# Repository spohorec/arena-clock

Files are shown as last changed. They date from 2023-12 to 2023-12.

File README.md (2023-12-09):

# Mass Destruction Arena Clock

A simple and robust solution for combat robotics arena-side match clock. The clock consists of a PCB for power + logic, 2 sets of 3x 6" seven-segment digits (one for competitors, one for audience viewing), and a nucleo-L412KB for control. The clock is controlled via USB UART and a python gui.

## READMEs

[Firmware README](firmware/README.md)

[GUI README](gui/README.md)

[PCB README](pcb/README.md)

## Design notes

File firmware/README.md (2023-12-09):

# Arena Clock Firmware

This firmware uses [platformio](https://platformio.org/) for build management. It runs on a [ST Nucleo-L412KB](https://www.st.com/en/evaluation-tools/nucleo-l412kb.html) on a custom carrier board (see [pcb](../pcb/)).

The CubeMX project configuration is generated in headless mode during the project build. You must change the value of the `CUBE` varibale in `lib/cube/generate_cube_code.sh` to point to your installation of STM32CubeMX. Note that this script will likely not work on a Windows machine without modification. If developing on Windows, the call to `generate_stm32_cube_sources()` in `extra.py` can be commented out and the required code can be manually generated using the STM32CubeMx GUI and then moved to `lib/cube/Src/` and `lib/cube/Inc`. The patch file adds an include directive to include `main_loop.h` and call `MainLoop()` after initialization is completed in `main()`. This can also be added manually.

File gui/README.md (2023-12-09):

# GUI To control clock

## Requirements

* Python 3.6 +
* Modules: PyQt5, sys, serial

## How to use:

Plug USB into nucleo and computer and run
`python3.6 gui.py [insert serial port here (COMX or /dev/ttyXYZ)]`

Type desired time (min:sec) into time entry. Click "set time" to send to the nucleo. The "clear" button zeroes the time on the clock. The start/pause button controls when the clock counts down. Once the timer has been started, it must count to zero or be cleared before a new time can be entered.

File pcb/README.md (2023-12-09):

# Arena Clock PCB

This PCB project was made with Kicad 6.0

## Bill of Materials

TODO

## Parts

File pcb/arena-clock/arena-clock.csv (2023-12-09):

Source: | /home/spocky/arena-clock/pcb/arena-clock/arena-clock.kicad_sch
Date: | Mon 20 Nov 2023 06:52:53 PM EST
Tool: | Eeschema 6.0.10-86aedd382b~118~ubuntu18.04.1
Generator: | /usr/share/kicad/plugins/bom_csv_grouped_by_value.py
Component Count: | 128
Individual Components:
Item | Qty | Reference(s) | Value | LibPart | Footprint | Datasheet
 |  | C1 | C_Small | Device:C_Small | Capacitor_SMD:C_0805_2012Metric_Pad1.18x1.45mm_HandSolder | ~
 |  | C2 | C_Small | Device:C_Small | Capacitor_SMD:C_0805_2012Metric_Pad1.18x1.45mm_HandSolder | ~
 |  | C3 | C_Small | Device:C_Small | Capacitor_SMD:C_0805_2012Metric_Pad1.18x1.45mm_HandSolder | ~
 |  | C4 | 10u | Device:C_Small | Capacitor_SMD:C_0805_2012Metric_Pad1.18x1.45mm_HandSolder | ~
 |  | C5 | 10u | Device:C_Small | Capacitor_SMD:C_0805_2012Metric_Pad1.18x1.45mm_HandSolder | ~
 |  | C6 | C_Small | Device:C_Small | Capacitor_SMD:C_0805_2012Metric_Pad1.18x1.45mm_HandSolder | ~
 |  | C7 | 0.1u | Device:C_Small | Capacitor_SMD:C_0805_2012Metric_Pad1.18x1.45mm_HandSolder | ~
 |  | C8 | 0.1u | Device:C_Small | Capacitor_SMD:C_0805_2012Metric_Pad1.18x1.45mm_HandSolder | ~
 |  | C9 | 0.1u | Device:C_Small | Capacitor_SMD:C_0805_2012Metric_Pad1.18x1.45mm_HandSolder | ~
 |  | C10 | 0.1u | Device:C_Small | Capacitor_SMD:C_0805_2012Metric_Pad1.18x1.45mm_HandSolder | ~
 |  | D1 | D_Schottky | Device:D_Schottky | Diode_THT:D_A-405_P7.62mm_Horizontal | ~
 |  | J1 | SPEAKER ENABLE | Connector_Generic:Conn_01x02 | TerminalBlock_Phoenix:TerminalBlock_Phoenix_PT-1,5-2-3.5-H_1x02_P3.50mm_Horizontal | ~
 |  | J2 | DIGIT1 | Connector_Generic:Conn_01x09 | TerminalBlock_Phoenix:TerminalBlock_Phoenix_PT-1,5-9-3.5-H_1x09_P3.50mm_Horizontal | ~
 |  | J3 | DIGIT2 | Connector_Generic:Conn_01x09 | TerminalBlock_Phoenix:TerminalBlock_Phoenix_PT-1,5-9-3.5-H_1x09_P3.50mm_Horizontal | ~
 |  | J4 | DIGIT3 | Connector_Generic:Conn_01x09 | TerminalBlock_Phoenix:TerminalBlock_Phoenix_PT-1,5-9-3.5-H_1x09_P3.50mm_Horizontal | ~
 |  | J5 | DIGIT4 | Connector_Generic:Conn_01x09 | TerminalBlock_Phoenix:TerminalBlock_Phoenix_PT-1,5-9-3.5-H_1x09_P3.50mm_Horizontal | ~
 |  | J6 | DIGIT5 | Connector_Generic:Conn_01x09 | TerminalBlock_Phoenix:TerminalBlock_Phoenix_PT-1,5-9-3.5-H_1x09_P3.50mm_Horizontal | ~
 |  | J7 | DIGIT6 | Connector_Generic:Conn_01x09 | TerminalBlock_Phoenix:TerminalBlock_Phoenix_PT-1,5-9-3.5-H_1x09_P3.50mm_Horizontal | ~
 |  | J8 | AUX 12V OUT | Connector_Generic:Conn_01x02 | Connector_PinHeader_2.54mm:PinHeader_1x02_P2.54mm_Vertical | ~
 |  | J9 | Conn_01x03_Male | Connector:Conn_01x03_Male | Connector_PinHeader_2.54mm:PinHeader_1x03_P2.54mm_Vertical | ~
 |  | J10 | Conn_01x03_Male | Connector:Conn_01x03_Male | Connector_PinHeader_2.54mm:PinHeader_1x03_P2.54mm_Vertical | ~
 |  | J11 | 12V POW CONN | Connector_Generic:Conn_01x02 | Connector_PinHeader_2.54mm:PinHeader_1x02_P2.54mm_Vertical | ~
 |  | J12 | 5V POW CONN | Connector_Generic:Conn_01x02 | Connector_PinHeader_2.54mm:PinHeader_1x02_P2.54mm_Vertical | ~
 |  | J13 | AUX SINK | Connector_Generic:Conn_01x06 | Connector_PinHeader_2.54mm:PinHeader_1x06_P2.54mm_Vertical | ~
 |  | J14 | AUX GPIO | Connector_Generic:Conn_01x05 | Connector_PinHeader_2.54mm:PinHeader_1x05_P2.54mm_Vertical | ~
 |  | J15 | Barrel_Jack | Connector:Barrel_Jack_Switch_MountingPin | Connector_BarrelJack:BarrelJack_Kycon_KLDX-0202-xC_Horizontal | ~
 |  | J16 | CN3 Breakout | Connector:Conn_01x15_Female | Connector_PinHeader_2.54mm:PinHeader_1x15_P2.54mm_Vertical | ~
 |  | J17 | CN3 | Connector:Conn_01x15_Female | Connector_PinHeader_2.54mm:PinHeader_1x15_P2.54mm_Vertical | ~
 |  | J18 | CN4 | Connector:Conn_01x15_Female | Connector_PinHeader_2.54mm:PinHeader_1x15_P2.54mm_Vertical | ~
 |  | J19 | CN4 Breakout | Connector:Conn_01x15_Female | Connector_PinHeader_2.54mm:PinHeader_1x15_P2.54mm_Vertical | ~
 |  | R1 | 0 | Device:R_Small | Resistor_SMD:R_0805_2012Metric_Pad1.20x1.40mm_HandSolder | ~
 |  | R2 | 100k | Device:R_Small | Resistor_SMD:R_0805_2012Metric_Pad1.20x1.40mm_HandSolder | ~
 |  | R3 | 100k | Device:R_Small | Resistor_SMD:R_0805_2012Metric_Pad1.20x1.40mm_HandSolder | ~
 |  | R4 | 0 | Device:R_Small | Resistor_SMD:R_0805_2012Metric_Pad1.20x1.40mm_HandSolder | ~
 |  | R5 | 100k | Device:R_Small | Resistor_SMD:R_0805_2012Metric_Pad1.20x1.40mm_HandSolder | ~
 |  | R6 | 100k | Device:R_Small | Resistor_SMD:R_0805_2012Metric_Pad1.20x1.40mm_HandSolder | ~
 |  | R7 | 0 | Device:R_Small | Resistor_SMD:R_0805_2012Metric_Pad1.20x1.40mm_HandSolder | ~
 |  | R8 | 15 | Device:R_Small | Resistor_SMD:R_0805_2012Metric_Pad1.20x1.40mm_HandSolder | ~
 |  | R9 | 15 | Device:R_Small | Resistor_SMD:R_0805_2012Metric_Pad1.20x1.40mm_HandSolder | ~
 |  | R10 | 15 | Device:R_Small | Resistor_SMD:R_0805_2012Metric_Pad1.20x1.40mm_HandSolder | ~
 |  | R11 | 15 | Device:R_Small | Resistor_SMD:R_0805_2012Metric_Pad1.20x1.40mm_HandSolder | ~
 |  | R12 | 15 | Device:R_Small | Resistor_SMD:R_0805_2012Metric_Pad1.20x1.40mm_HandSolder | ~
 |  | R13 | 15 | Device:R_Small | Resistor_SMD:R_0805_2012Metric_Pad1.20x1.40mm_HandSolder | ~
 |  | R14 | 15 | Device:R_Small | Resistor_SMD:R_0805_2012Metric_Pad1.20x1.40mm_HandSolder | ~
 |  | R15 | 15 | Device:R_Small | Resistor_SMD:R_0805_2012Metric_Pad1.20x1.40mm_HandSolder | ~
 |  | R16 | 15 | Device:R_Small | Resistor_SMD:R_0805_2012Metric_Pad1.20x1.40mm_HandSolder | ~
 |  | R17 | 15 | Device:R_Small | Resistor_SMD:R_0805_2012Metric_Pad1.20x1.40mm_HandSolder | ~
 |  | R18 | 15 | Device:R_Small | Resistor_SMD:R_0805_2012Metric_Pad1.20x1.40mm_HandSolder | ~
 |  | R19 | 15 | Device:R_Small | Resistor_SMD:R_0805_2012Metric_Pad1.20x1.40mm_HandSolder | ~
 |  | R20 | 15 | Device:R_Small | Resistor_SMD:R_0805_2012Metric_Pad1.20x1.40mm_HandSolder | ~
 |  | R21 | 15 | Device:R_Small | Resistor_SMD:R_0805_2012Metric_Pad1.20x1.40mm_HandSolder | ~
 |  | R22 | 15 | Device:R_Small | Resistor_SMD:R_0805_2012Metric_Pad1.20x1.40mm_HandSolder | ~
 |  | R23 | 15 | Device:R_Small | Resistor_SMD:R_0805_2012Metric_Pad1.20x1.40mm_HandSolder | ~
 |  | R24 | 15 | Device:R_Small | Resistor_SMD:R_0805_2012Metric_Pad1.20x1.40mm_HandSolder | ~
 |  | R25 | 15 | Device:R_Small | Resistor_SMD:R_0805_2012Metric_Pad1.20x1.40mm_HandSolder | ~
 |  | R26 | 15 | Device:R_Small | Resistor_SMD:R_0805_2012Metric_Pad1.20x1.40mm_HandSolder | ~
 |  | R27 | 15 | Device:R_Small | Resistor_SMD:R_0805_2012Metric_Pad1.20x1.40mm_HandSolder | ~
 |  | R28 | 15 | Device:R_Small | Resistor_SMD:R_0805_2012Metric_Pad1.20x1.40mm_HandSolder | ~
 |  | R29 | 15 | Device:R_Small | Resistor_SMD:R_0805_2012Metric_Pad1.20x1.40mm_HandSolder | ~
 |  | R30 | 15 | Device:R_Small | Resistor_SMD:R_0805_2012Metric_Pad1.20x1.40mm_HandSolder | ~
 |  | R31 | 15 | Device:R_Small | Resistor_SMD:R_0805_2012Metric_Pad1.20x1.40mm_HandSolder | ~
 |  | R32 | 15 | Device:R_Small | Resistor_SMD:R_0805_2012Metric_Pad1.20x1.40mm_HandSolder | ~
 |  | R33 | 15 | Device:R_Small | Resistor_SMD:R_0805_2012Metric_Pad1.20x1.40mm_HandSolder | ~
 |  | R34 | 15 | Device:R_Small | Resistor_SMD:R_0805_2012Metric_Pad1.20x1.40mm_HandSolder | ~
 |  | R35 | 15 | Device:R_Small | Resistor_SMD:R_0805_2012Metric_Pad1.20x1.40mm_HandSolder | ~
 |  | R36 | 15 | Device:R_Small | Resistor_SMD:R_0805_2012Metric_Pad1.20x1.40mm_HandSolder | ~
 |  | R37 | 15 | Device:R_Small | Resistor_SMD:R_0805_2012Metric_Pad1.20x1.40mm_HandSolder | ~
 |  | R38 | 15 | Device:R_Small | Resistor_SMD:R_0805_2012Metric_Pad1.20x1.40mm_HandSolder | ~
 |  | R39 | 15 | Device:R_Small | Resistor_SMD:R_0805_2012Metric_Pad1.20x1.40mm_HandSolder | ~
 |  | R40 | 15 | Device:R_Small | Resistor_SMD:R_0805_2012Metric_Pad1.20x1.40mm_HandSolder | ~
 |  | R41 | 15 | Device:R_Small | Resistor_SMD:R_0805_2012Metric_Pad1.20x1.40mm_HandSolder | ~
 |  | R42 | 15 | Device:R_Small | Resistor_SMD:R_0805_2012Metric_Pad1.20x1.40mm_HandSolder | ~
 |  | R43 | 15 | Device:R_Small | Resistor_SMD:R_0805_2012Metric_Pad1.20x1.40mm_HandSolder | ~
 |  | R44 | 15 | Device:R_Small | Resistor_SMD:R_0805_2012Metric_Pad1.20x1.40mm_HandSolder | ~
 |  | R45 | 15 | Device:R_Small | Resistor_SMD:R_0805_2012Metric_Pad1.20x1.40mm_HandSolder | ~
 |  | R46 | 15 | Device:R_Small | Resistor_SMD:R_0805_2012Metric_Pad1.20x1.40mm_HandSolder | ~
 |  | R47 | 15 | Device:R_Small | Resistor_SMD:R_0805_2012Metric_Pad1.20x1.40mm_HandSolder | ~
 |  | R48 | 15 | Device:R_Small | Resistor_SMD:R_0805_2012Metric_Pad1.20x1.40mm_HandSolder | ~
 |  | R49 | 15 | Device:R_Small | Resistor_SMD:R_0805_2012Metric_Pad1.20x1.40mm_HandSolder | ~
 |  | R50 | 15 | Device:R_Small | Resistor_SMD:R_0805_2012Metric_Pad1.20x1.40mm_HandSolder | ~
 |  | R51 | 15 | Device:R_Small | Resistor_SMD:R_0805_2012Metric_Pad1.20x1.40mm_HandSolder | ~
 |  | R52 | 15 | Device:R_Small | Resistor_SMD:R_0805_2012Metric_Pad1.20x1.40mm_HandSolder | ~
 |  | R53 | 15 | Device:R_Small | Resistor_SMD:R_0805_2012Metric_Pad1.20x1.40mm_HandSolder | ~
 |  | R54 | 15 | Device:R_Small | Resistor_SMD:R_0805_2012Metric_Pad1.20x1.40mm_HandSolder | ~
 |  | R55 | 15 | Device:R_Small | Resistor_SMD:R_0805_2012Metric_Pad1.20x1.40mm_HandSolder | ~
 |  | R56 | 0 | Device:R_Small | Resistor_SMD:R_0805_2012Metric_Pad1.20x1.40mm_HandSolder | ~
 |  | R57 | 0 | Device:R_Small | Resistor_SMD:R_0805_2012Metric_Pad1.20x1.40mm_HandSolder | ~
 |  | R58 | 0 | Device:R_Small | Resistor_SMD:R_0805_2012Metric_Pad1.20x1.40mm_HandSolder | ~
 |  | R59 | 0 | Device:R_Small | Resistor_SMD:R_0805_2012Metric_Pad1.20x1.40mm_HandSolder | ~
 |  | R60 | 0 | Device:R_Small | Resistor_SMD:R_0805_2012Metric_Pad1.20x1.40mm_HandSolder | ~
 |  | R61 | 0 | Device:R_Small | Resistor_SMD:R_0805_2012Metric_Pad1.20x1.40mm_HandSolder | ~
 |  | R62 | 0 | Device:R_Small | Resistor_SMD:R_0805_2012Metric_Pad1.20x1.40mm_HandSolder | ~
 |  | R63 | 120 | Device:R_Small | Resistor_SMD:R_0805_2012Metric_Pad1.20x1.40mm_HandSolder | ~
 |  | R64 | 120 | Device:R_Small | Resistor_SMD:R_0805_2012Metric_Pad1.20x1.40mm_HandSolder | ~
 |  | R65 | 120 | Device:R_Small | Resistor_SMD:R_0805_2012Metric_Pad1.20x1.40mm_HandSolder | ~
 |  | R66 | 120 | Device:R_Small | Resistor_SMD:R_0805_2012Metric_Pad1.20x1.40mm_HandSolder | ~
 |  | R67 | 120 | Device:R_Small | Resistor_SMD:R_0805_2012Metric_Pad1.20x1.40mm_HandSolder | ~
 |  | R68 | 120 | Device:R_Small | Resistor_SMD:R_0805_2012Metric_Pad1.20x1.40mm_HandSolder | ~
 |  | R69 | 120 | Device:R_Small | Resistor_SMD:R_0805_2012Metric_Pad1.20x1.40mm_HandSolder | ~
 |  | R70 | 120 | Device:R_Small | Resistor_SMD:R_0805_2012Metric_Pad1.20x1.40mm_HandSolder | ~
 |  | R71 | 120 | Device:R_Small | Resistor_SMD:R_0805_2012Metric_Pad1.20x1.40mm_HandSolder | ~
 |  | R72 | 120 | Device:R_Small | Resistor_SMD:R_0805_2012Metric_Pad1.20x1.40mm_HandSolder | ~
 |  | R73 | 120 | Device:R_Small | Resistor_SMD:R_0805_2012Metric_Pad1.20x1.40mm_HandSolder | ~
 |  | R74 | 120 | Device:R_Small | Resistor_SMD:R_0805_2012Metric_Pad1.20x1.40mm_HandSolder | ~
 |  | R75 | 120 | Device:R_Small | Resistor_SMD:R_0805_2012Metric_Pad1.20x1.40mm_HandSolder | ~
 |  | R76 | 120 | Device:R_Small | Resistor_SMD:R_0805_2012Metric_Pad1.20x1.40mm_HandSolder | ~
 |  | R77 | 120 | Device:R_Small | Resistor_SMD:R_0805_2012Metric_Pad1.20x1.40mm_HandSolder | ~
 |  | R78 | 120 | Device:R_Small | Resistor_SMD:R_0805_2012Metric_Pad1.20x1.40mm_HandSolder | ~
 |  | R79 | 120 | Device:R_Small | Resistor_SMD:R_0805_2012Metric_Pad1.20x1.40mm_HandSolder | ~
 |  | R80 | 120 | Device:R_Small | Resistor_SMD:R_0805_2012Metric_Pad1.20x1.40mm_HandSolder | ~
 |  | R81 | 120 | Device:R_Small | Resistor_SMD:R_0805_2012Metric_Pad1.20x1.40mm_HandSolder | ~
 |  | R82 | 120 | Device:R_Small | Resistor_SMD:R_0805_2012Metric_Pad1.20x1.40mm_HandSolder | ~
 |  | R83 | 120 | Device:R_Small | Resistor_SMD:R_0805_2012Metric_Pad1.20x1.40mm_HandSolder | ~
 |  | R84 | 120 | Device:R_Small | Resistor_SMD:R_0805_2012Metric_Pad1.20x1.40mm_HandSolder | ~
 |  | R85 | 120 | Device:R_Small | Resistor_SMD:R_0805_2012Metric_Pad1.20x1.40mm_HandSolder | ~
 |  | R86 | 120 | Device:R_Small | Resistor_SMD:R_0805_2012Metric_Pad1.20x1.40mm_HandSolder | ~
 |  | U1 | TPIC6595 | :TPIC6C596_3 | Package_DIP:DIP-16_W7.62mm | http://www.ti.com/lit/ds/symlink/tpic6595.pdf
 |  | U2 | TPIC6595 | :TPIC6C596_1 | Package_DIP:DIP-16_W7.62mm | http://www.ti.com/lit/ds/symlink/tpic6595.pdf
 |  | U3 | TPIC6595 | :TPIC6C596_2 | Package_DIP:DIP-16_W7.62mm | http://www.ti.com/lit/ds/symlink/tpic6595.pdf
 |  | U4 | J107F1CS1212VDC.36 | project-components:J107F1CS1212VDC.36 | Relay_THT:Relay_SPDT_Finder_36.11
 |  | U5 | J107F1CS1212VDC.36 | project-components:J107F1CS1212VDC.36 | Relay_THT:Relay_SPDT_Finder_36.11
 |  | U6 | HDSP-7501 | Display_Character:HDSP-7501 | Display_7Segment:HDSP-A151 | https://docs.broadcom.com/docs/AV02-2553EN
 |  | U7 | HDSP-7501 | Display_Character:HDSP-7501 | Display_7Segment:HDSP-A151 | https://docs.broadcom.com/docs/AV02-2553EN
 |  | U8 | HDSP-7501 | Display_Character:HDSP-7501 | Display_7Segment:HDSP-A151 | https://docs.broadcom.com/docs/AV02-2553EN
 |  | U9 | BD50FD0WFP | project-components:BD50FD0WFP | Package_TO_SOT_SMD:TO-263-5 | https://fscdn.rohm.com/en/products/databook/datasheet/ic/power/linear_regulator/bdxxfd0xxxx-e.pdf
 |  | U10 | TPIC6595 | project-components:TPIC6C596 | Package_DIP:DIP-16_W7.62mm | http://www.ti.com/lit/ds/symlink/tpic6595.pdf
 |  | U11 | TXU0104 | project-components:TXU0104 | Package_SO:TSSOP-14_4.4x5mm_P0.65mm
 |  | U12 | TXU0104 | project-components:TXU0104 | Package_SO:TSSOP-14_4.4x5mm_P0.65mm
Collated Components:
Item | Qty | Reference(s) | Value | LibPart | Footprint | Datasheet
1 | 4 | C1, C2, C3, C6 | C_Small | Device:C_Small | Capacitor_SMD:C_0805_2012Metric_Pad1.18x1.45mm_HandSolder | ~
2 | 2 | C4, C5 | 10u | Device:C_Small | Capacitor_SMD:C_0805_2012Metric_Pad1.18x1.45mm_HandSolder | ~
3 | 4 | C7, C8, C9, C10 | 0.1u | Device:C_Small | Capacitor_SMD:C_0805_2012Metric_Pad1.18x1.45mm_HandSolder | ~
4 | 1 | D1 | D_Schottky | Device:D_Schottky | Diode_THT:D_A-405_P7.62mm_Horizontal | ~
5 | 1 | J1 | SPEAKER ENABLE | Connector_Generic:Conn_01x02 | TerminalBlock_Phoenix:TerminalBlock_Phoenix_PT-1,5-2-3.5-H_1x02_P3.50mm_Horizontal | ~
6 | 1 | J2 | DIGIT1 | Connector_Generic:Conn_01x09 | TerminalBlock_Phoenix:TerminalBlock_Phoenix_PT-1,5-9-3.5-H_1x09_P3.50mm_Horizontal | ~
7 | 1 | J3 | DIGIT2 | Connector_Generic:Conn_01x09 | TerminalBlock_Phoenix:TerminalBlock_Phoenix_PT-1,5-9-3.5-H_1x09_P3.50mm_Horizontal | ~
8 | 1 | J4 | DIGIT3 | Connector_Generic:Conn_01x09 | TerminalBlock_Phoenix:TerminalBlock_Phoenix_PT-1,5-9-3.5-H_1x09_P3.50mm_Horizontal | ~
9 | 1 | J5 | DIGIT4 | Connector_Generic:Conn_01x09 | TerminalBlock_Phoenix:TerminalBlock_Phoenix_PT-1,5-9-3.5-H_1x09_P3.50mm_Horizontal | ~
10 | 1 | J6 | DIGIT5 | Connector_Generic:Conn_01x09 | TerminalBlock_Phoenix:TerminalBlock_Phoenix_PT-1,5-9-3.5-H_1x09_P3.50mm_Horizontal | ~
11 | 1 | J7 | DIGIT6 | Connector_Generic:Conn_01x09 | TerminalBlock_Phoenix:TerminalBlock_Phoenix_PT-1,5-9-3.5-H_1x09_P3.50mm_Horizontal | ~
12 | 1 | J8 | AUX 12V OUT | Connector_Generic:Conn_01x02 | Connector_PinHeader_2.54mm:PinHeader_1x02_P2.54mm_Vertical | ~
13 | 2 | J9, J10 | Conn_01x03_Male | Connector:Conn_01x03_Male | Connector_PinHeader_2.54mm:PinHeader_1x03_P2.54mm_Vertical | ~
14 | 1 | J11 | 12V POW CONN | Connector_Generic:Conn_01x02 | Connector_PinHeader_2.54mm:PinHeader_1x02_P2.54mm_Vertical | ~
15 | 1 | J12 | 5V POW CONN | Connector_Generic:Conn_01x02 | Connector_PinHeader_2.54mm:PinHeader_1x02_P2.54mm_Vertical | ~
16 | 1 | J13 | AUX SINK | Connector_Generic:Conn_01x06 | Connector_PinHeader_2.54mm:PinHeader_1x06_P2.54mm_Vertical | ~
17 | 1 | J14 | AUX GPIO | Connector_Generic:Conn_01x05 | Connector_PinHeader_2.54mm:PinHeader_1x05_P2.54mm_Vertical | ~
18 | 1 | J15 | Barrel_Jack | Connector:Barrel_Jack_Switch_MountingPin | Connector_BarrelJack:BarrelJack_Kycon_KLDX-0202-xC_Horizontal | ~
19 | 1 | J16 | CN3 Breakout | Connector:Conn_01x15_Female | Connector_PinHeader_2.54mm:PinHeader_1x15_P2.54mm_Vertical | ~
20 | 1 | J17 | CN3 | Connector:Conn_01x15_Female | Connector_PinHeader_2.54mm:PinHeader_1x15_P2.54mm_Vertical | ~
21 | 1 | J18 | CN4 | Connector:Conn_01x15_Female | Connector_PinHeader_2.54mm:PinHeader_1x15_P2.54mm_Vertical | ~
22 | 1 | J19 | CN4 Breakout | Connector:Conn_01x15_Female | Connector_PinHeader_2.54mm:PinHeader_1x15_P2.54mm_Vertical | ~
23 | 10 | R1, R4, R7, R56, R57, R58, R59, R60, R61, R62 | 0 | Device:R_Small | Resistor_SMD:R_0805_2012Metric_Pad1.20x1.40mm_HandSolder | ~
24 | 4 | R2, R3, R5, R6 | 100k | Device:R_Small | Resistor_SMD:R_0805_2012Metric_Pad1.20x1.40mm_HandSolder | ~
25 | 48 | R8, R9, R10, R11, R12, R13, R14, R15, R16, R17, R18, R19, R20, R21, R22, R23, R24, R25, R26, R27, R28, R29, R30, R31, R32, R33, R34, R35, R36, R37, R38, R39, R40, R41, R42, R43, R44, R45, R46, R47, R48, R49, R50, R51, R52, R53, R54, R55 | 15 | Device:R_Small | Resistor_SMD:R_0805_2012Metric_Pad1.20x1.40mm_HandSolder | ~
26 | 24 | R63, R64, R65, R66, R67, R68, R69, R70, R71, R72, R73, R74, R75, R76, R77, R78, R79, R80, R81, R82, R83, R84, R85, R86 | 120 | Device:R_Small | Resistor_SMD:R_0805_2012Metric_Pad1.20x1.40mm_HandSolder | ~
27 | 1 | U1 | TPIC6595 | :TPIC6C596_3 | Package_DIP:DIP-16_W7.62mm | http://www.ti.com/lit/ds/symlink/tpic6595.pdf
28 | 1 | U2 | TPIC6595 | :TPIC6C596_1 | Package_DIP:DIP-16_W7.62mm | http://www.ti.com/lit/ds/symlink/tpic6595.pdf
29 | 1 | U3 | TPIC6595 | :TPIC6C596_2 | Package_DIP:DIP-16_W7.62mm | http://www.ti.com/lit/ds/symlink/tpic6595.pdf
30 | 2 | U4, U5 | J107F1CS1212VDC.36 | project-components:J107F1CS1212VDC.36 | Relay_THT:Relay_SPDT_Finder_36.11
31 | 3 | U6, U7, U8 | HDSP-7501 | Display_Character:HDSP-7501 | Display_7Segment:HDSP-A151 | https://docs.broadcom.com/docs/AV02-2553EN
32 | 1 | U9 | BD50FD0WFP | project-components:BD50FD0WFP | Package_TO_SOT_SMD:TO-263-5 | https://fscdn.rohm.com/en/products/databook/datasheet/ic/power/linear_regulator/bdxxfd0xxxx-e.pdf
33 | 1 | U10 | TPIC6595 | project-components:TPIC6C596 | Package_DIP:DIP-16_W7.62mm | http://www.ti.com/lit/ds/symlink/tpic6595.pdf
34 | 2 | U11, U12 | TXU0104 | project-components:TXU0104 | Package_SO:TSSOP-14_4.4x5mm_P0.65mm

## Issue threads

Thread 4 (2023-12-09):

Clean up PCB files

spohorec, 2023-12-09:
- [ ] Add values to unspecified passives; some passives were spec'd but not labelled as such in the schematic. Fix this,
- [ ] Fix incorrect reserve polarity diode footprint (too small)
- [ ] update resistor values to those actually used.

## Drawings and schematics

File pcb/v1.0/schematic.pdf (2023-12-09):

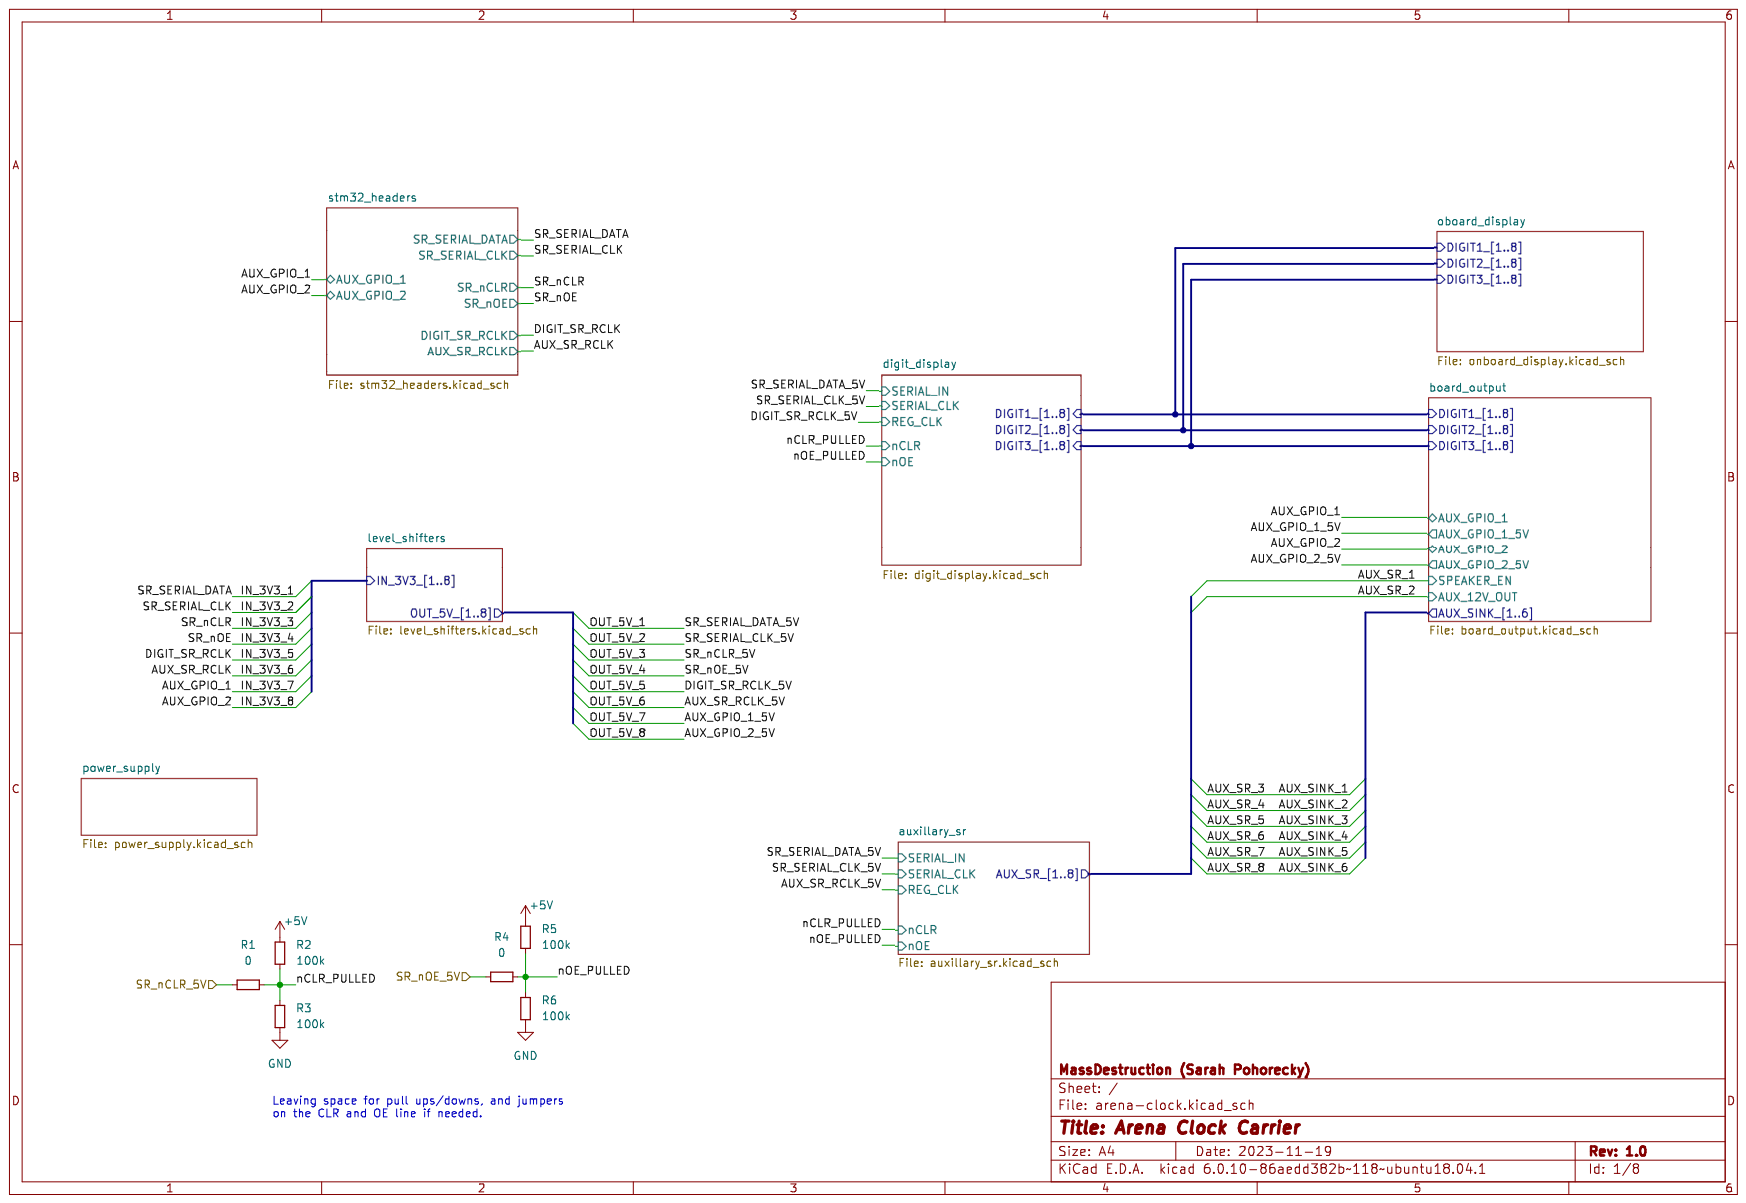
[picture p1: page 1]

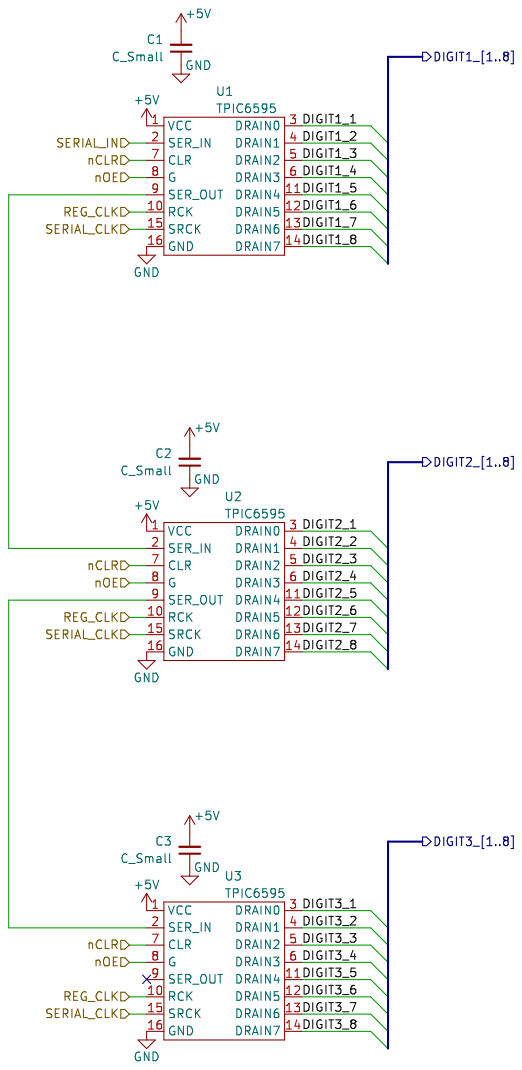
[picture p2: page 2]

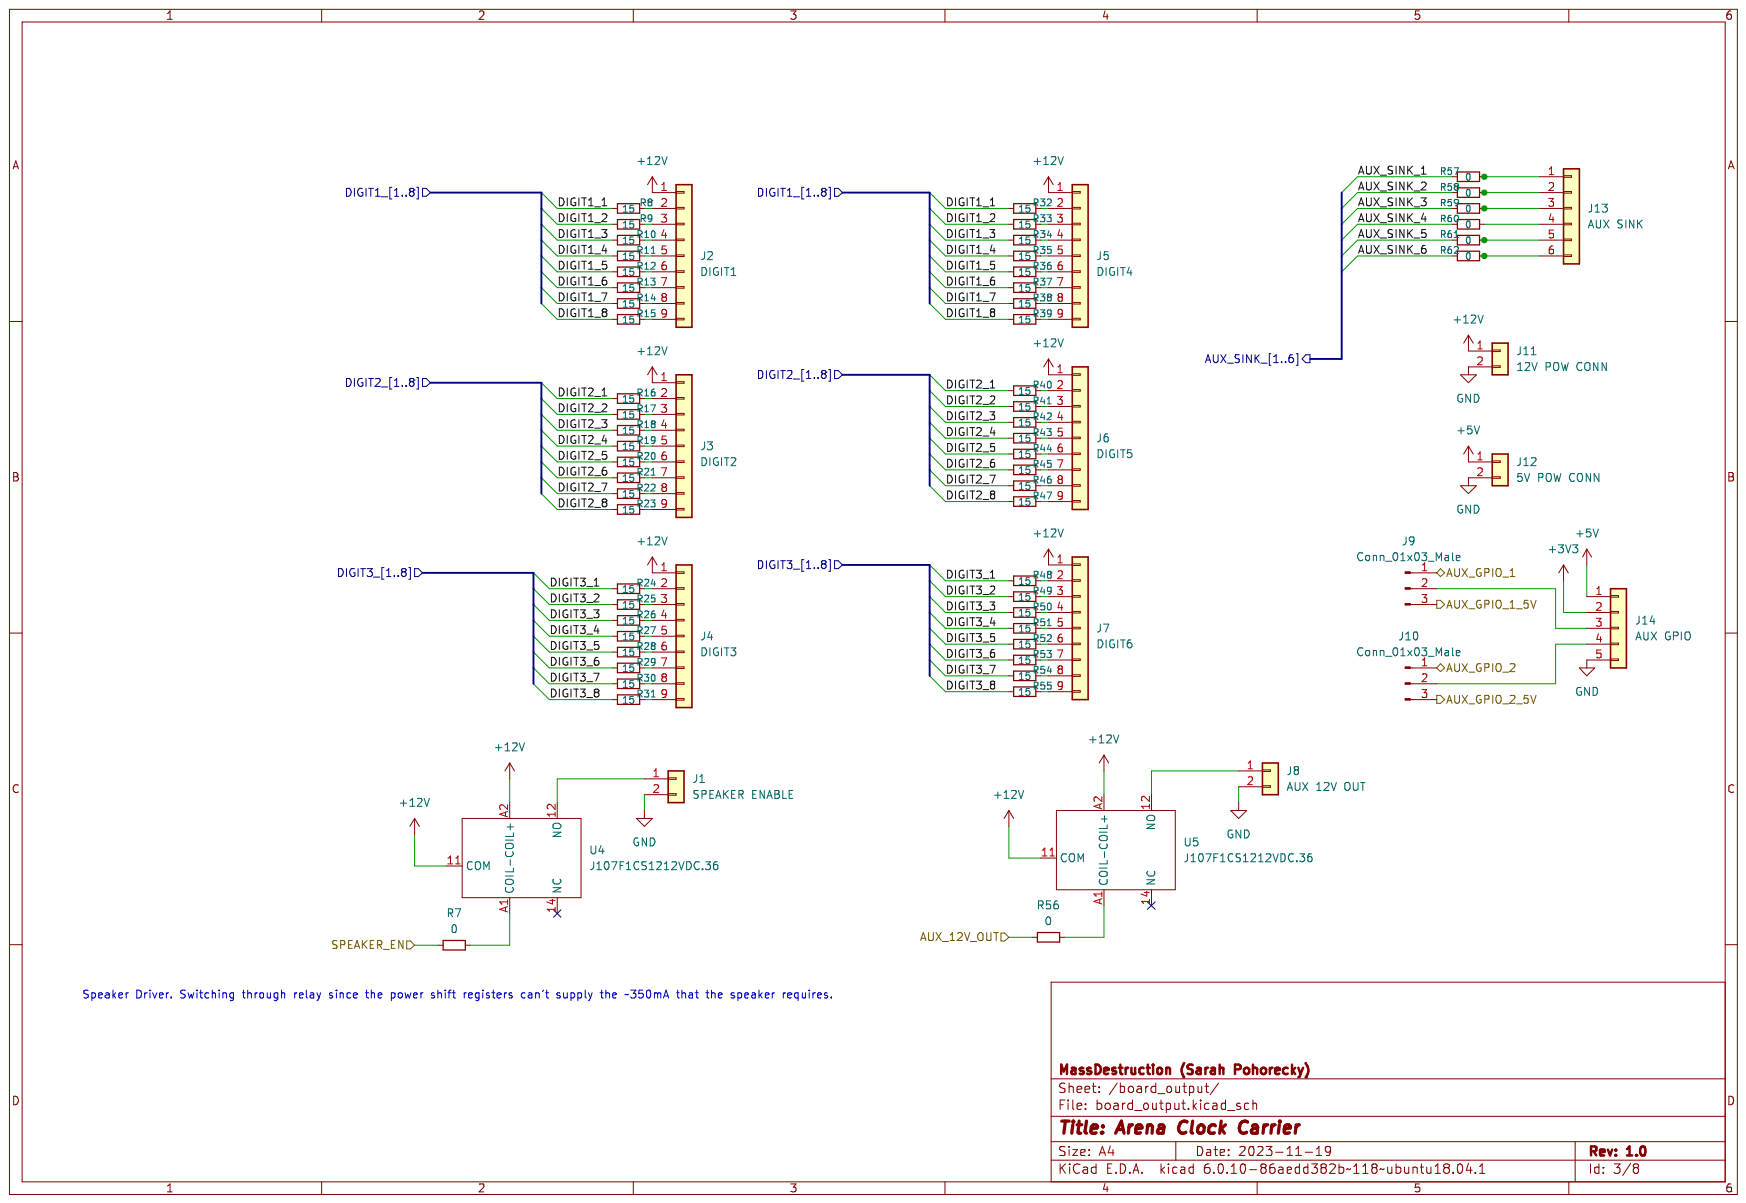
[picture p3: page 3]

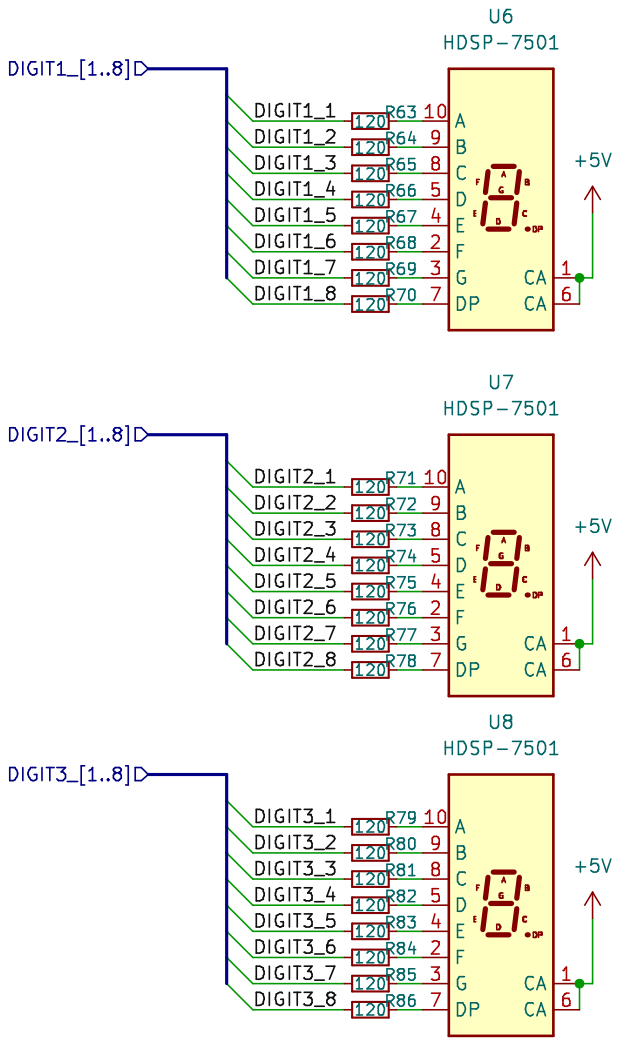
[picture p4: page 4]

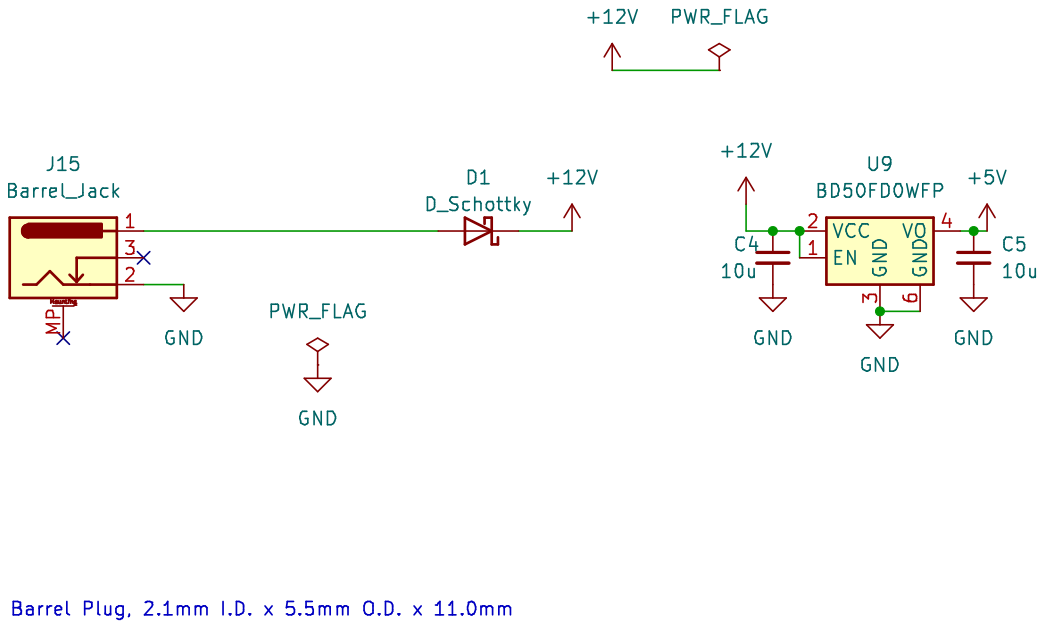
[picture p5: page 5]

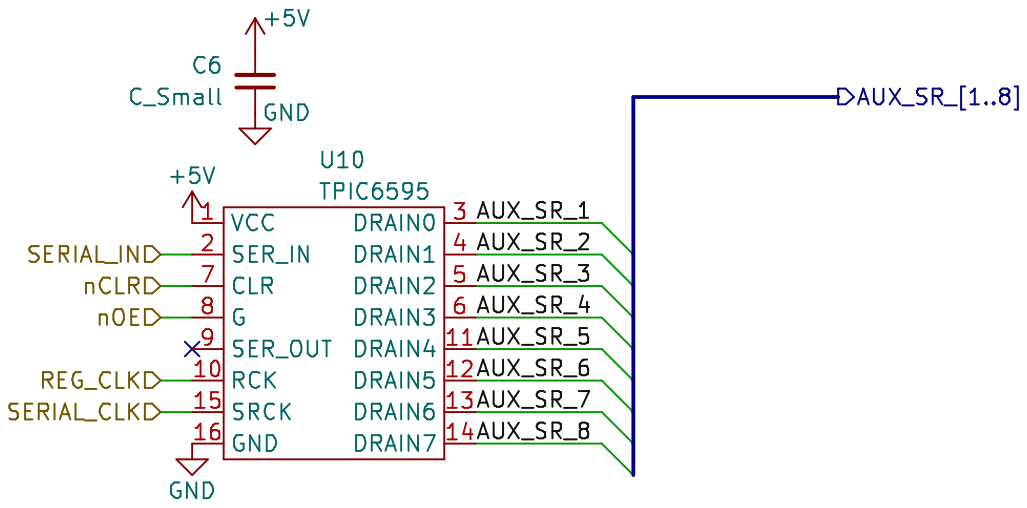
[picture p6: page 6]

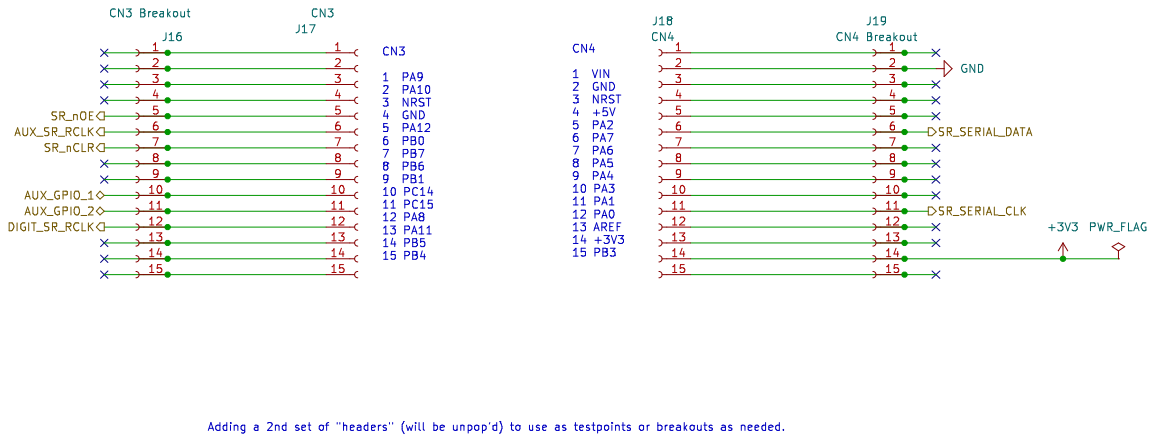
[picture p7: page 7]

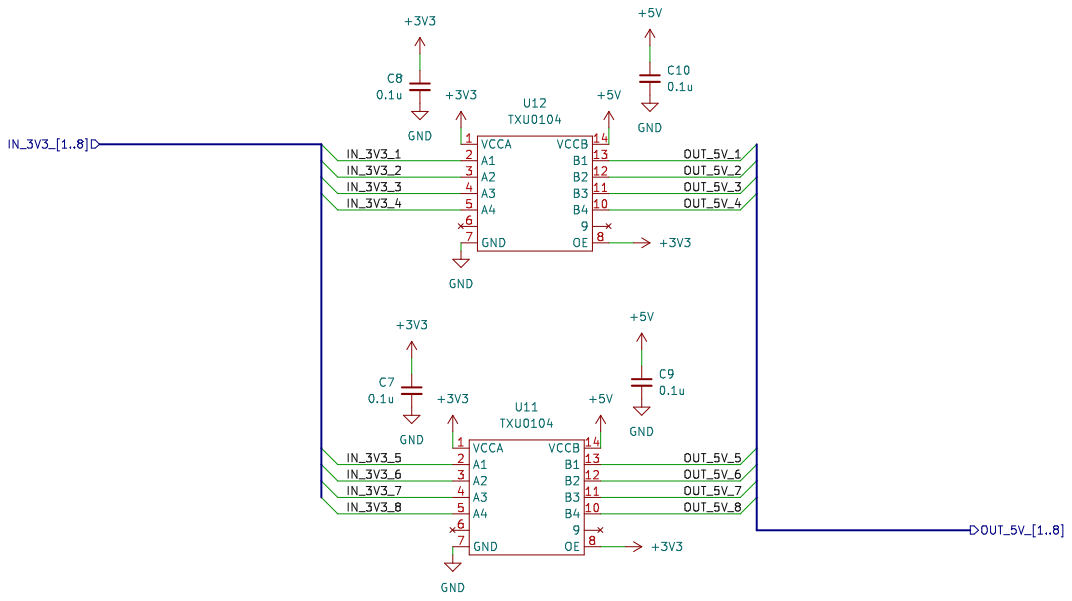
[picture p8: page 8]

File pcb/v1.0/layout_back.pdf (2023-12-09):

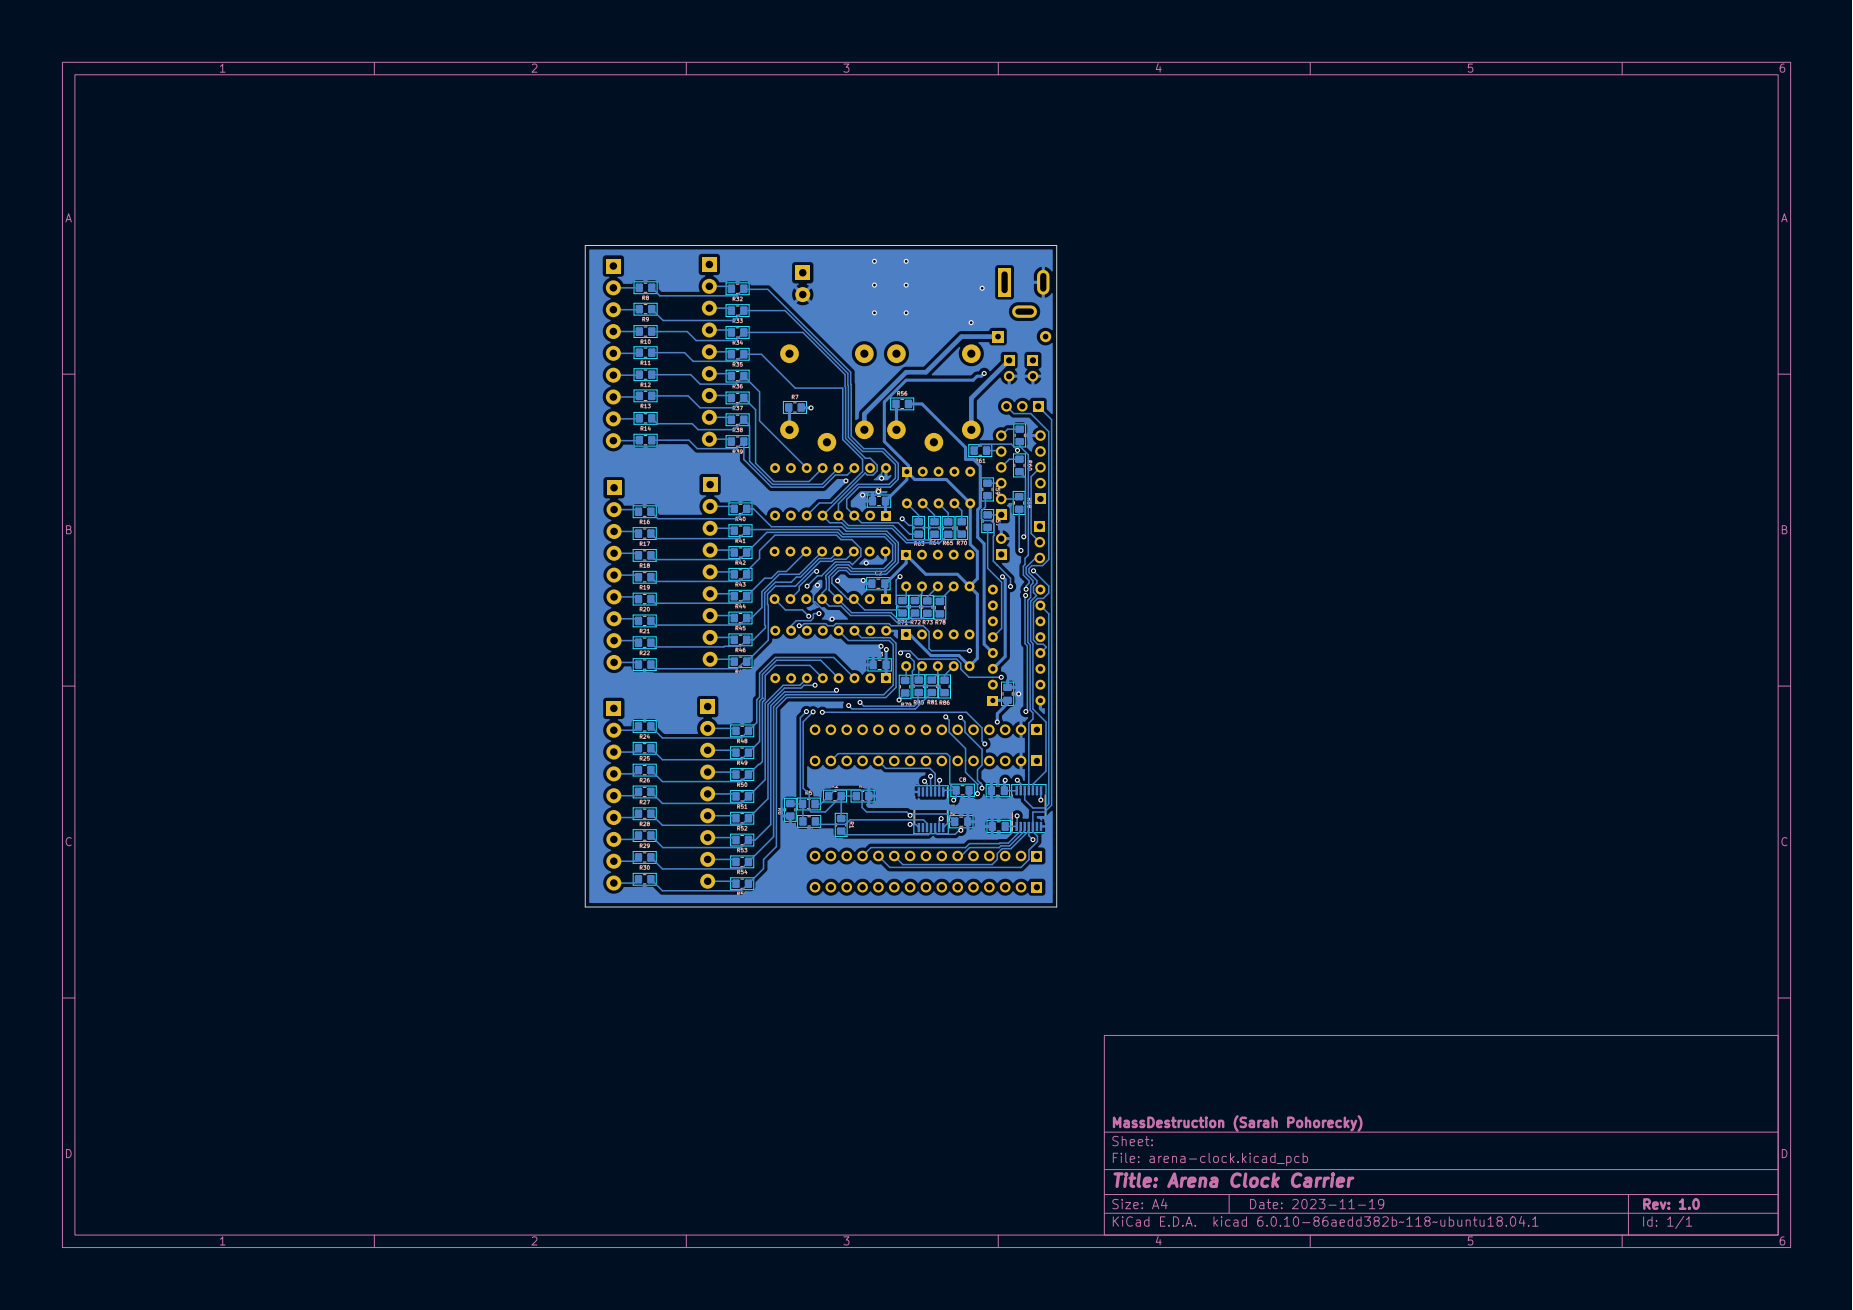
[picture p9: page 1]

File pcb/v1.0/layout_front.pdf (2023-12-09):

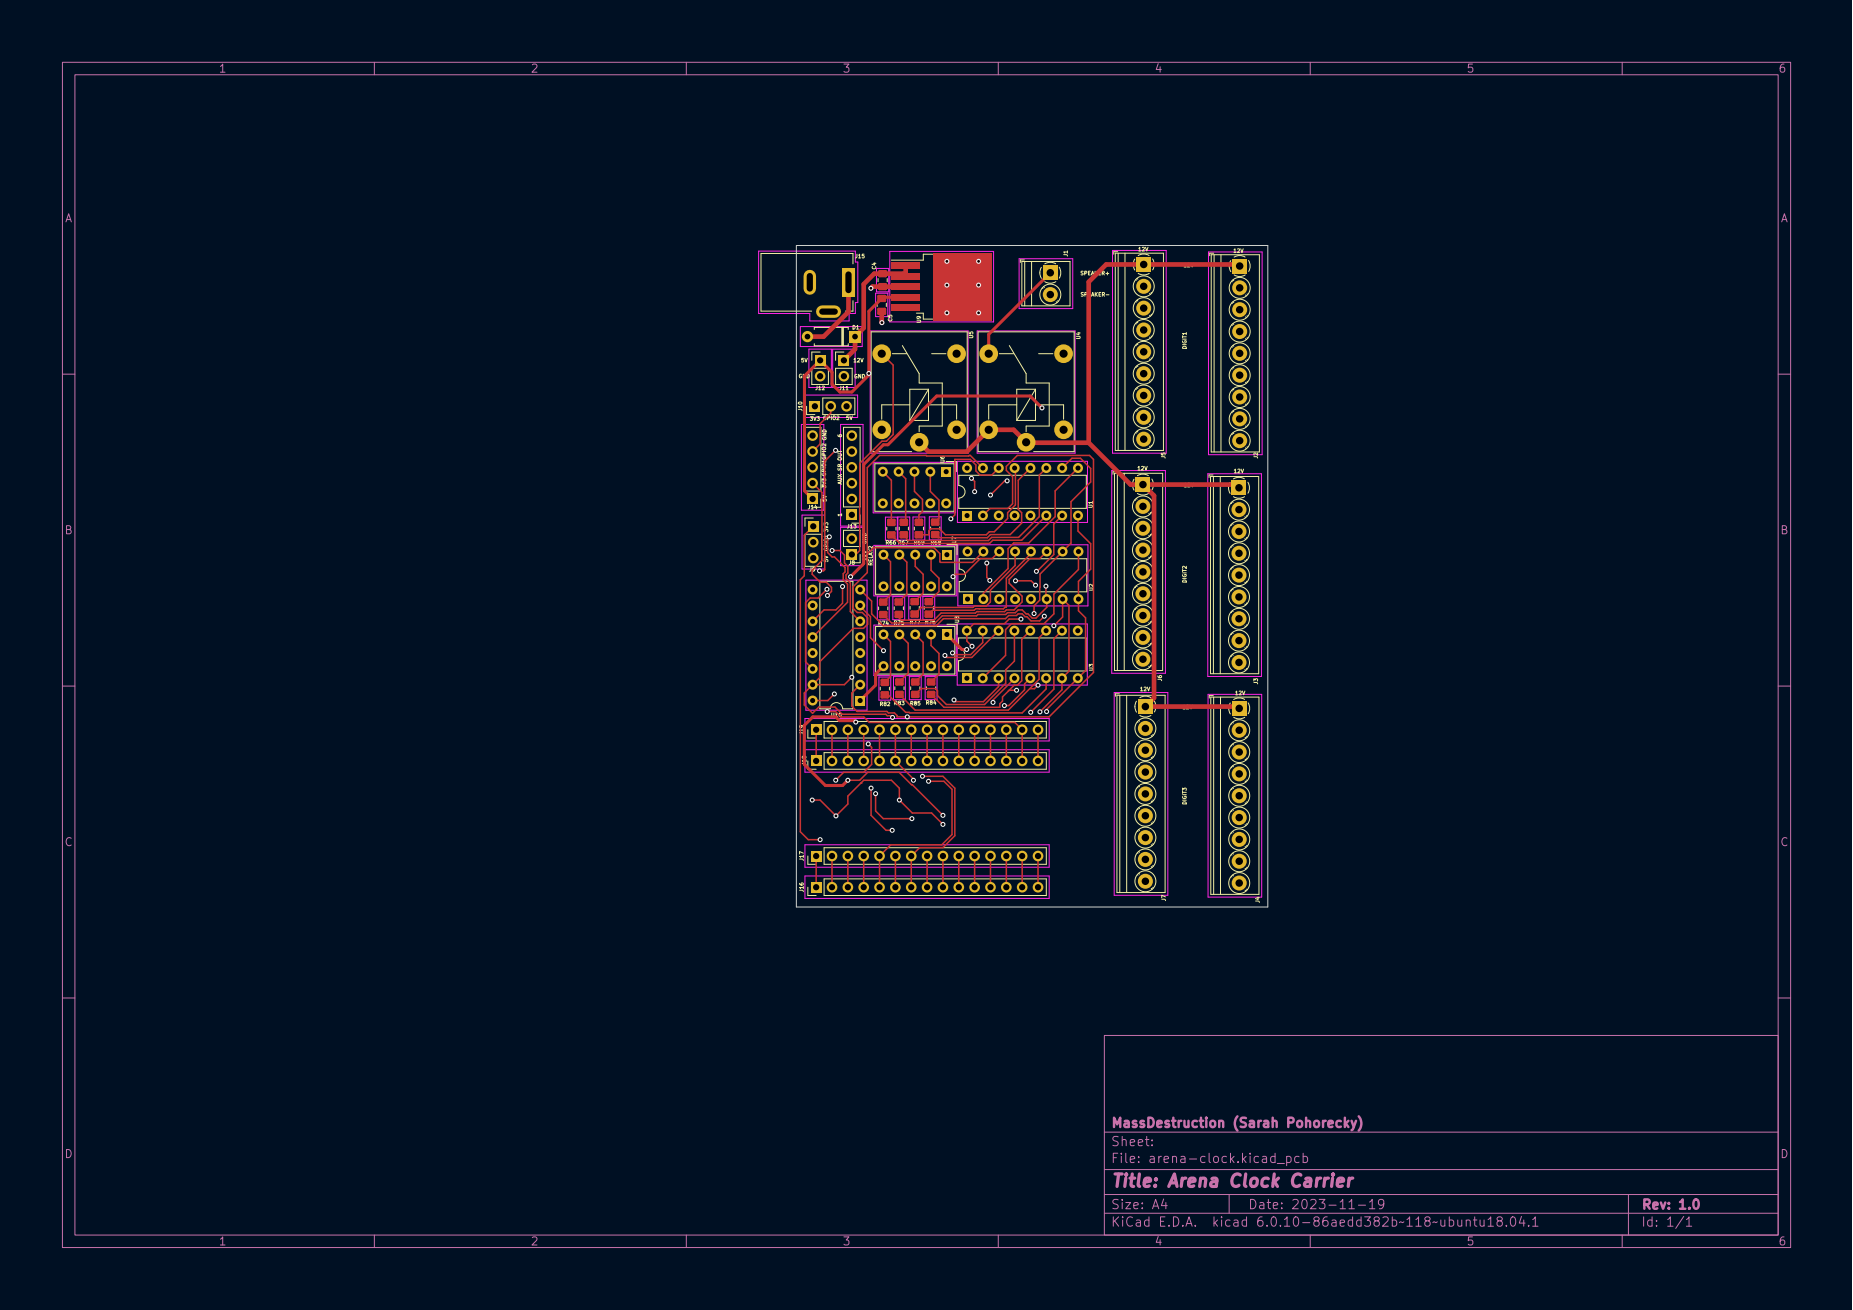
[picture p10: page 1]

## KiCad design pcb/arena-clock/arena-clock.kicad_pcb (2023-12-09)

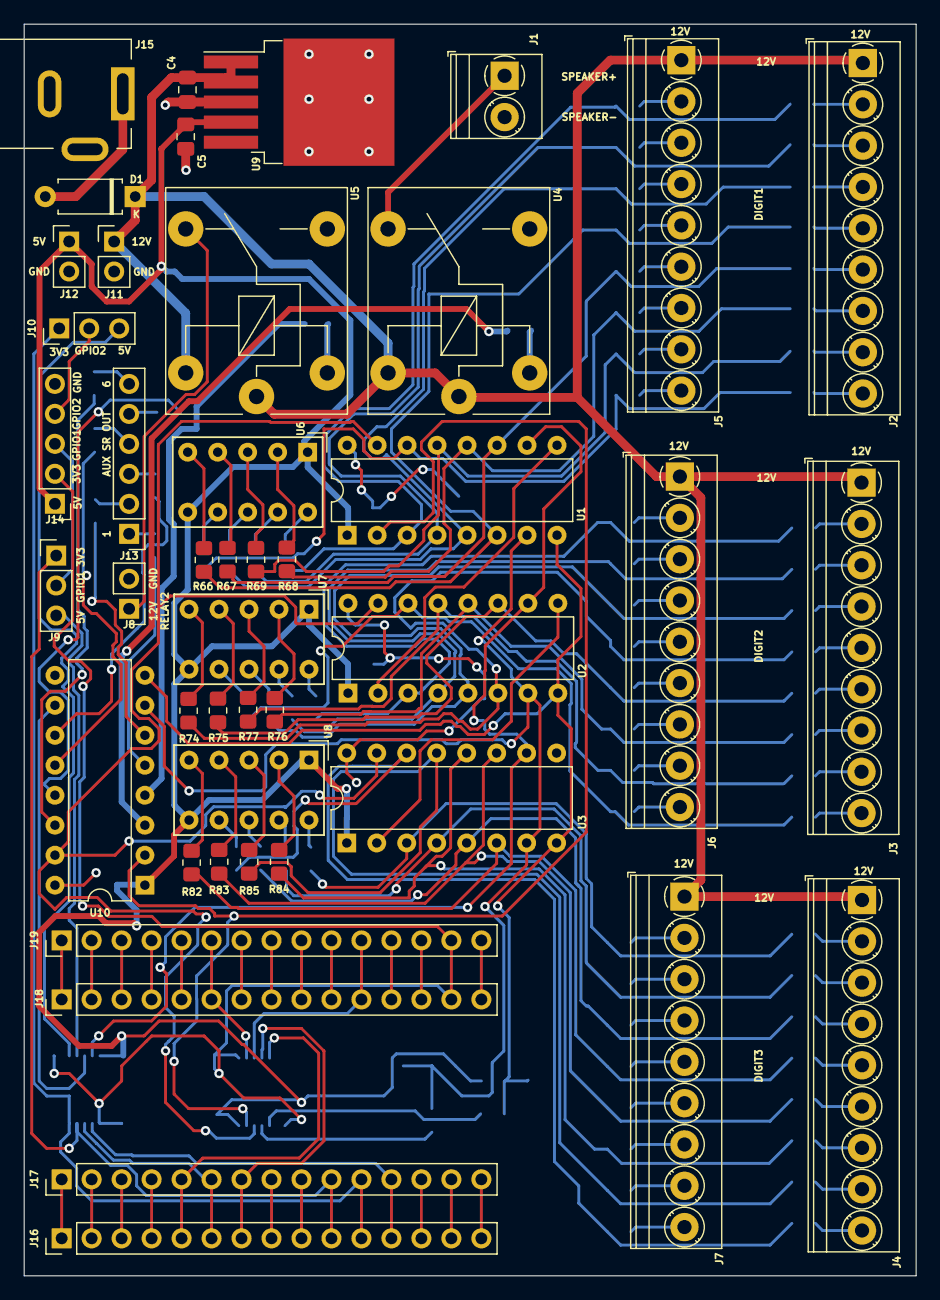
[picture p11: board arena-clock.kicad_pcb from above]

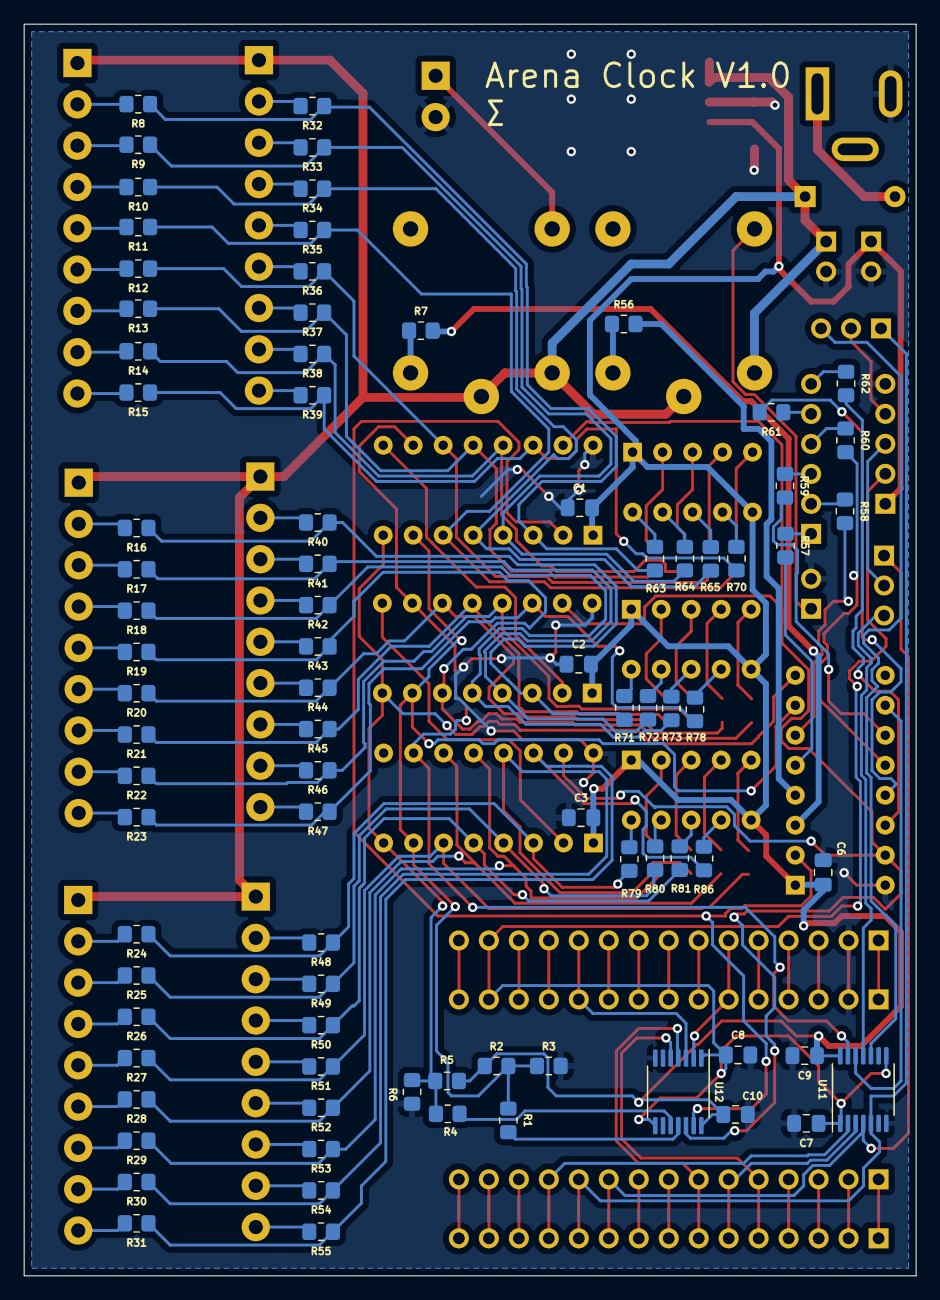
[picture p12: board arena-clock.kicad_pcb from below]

Board: 2 copper layers, 75.6 x 106.0 mm, 128 parts (84 on the bottom side), 141 nets.

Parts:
C1, C2, C3, C6: C_Small; C_0805_2012Metric_Pad1.18x1.45mm_HandSolder
C4, C5: 10u; C_0805_2012Metric_Pad1.18x1.45mm_HandSolder
C7, C8, C9, C10: 0.1u; C_0805_2012Metric_Pad1.18x1.45mm_HandSolder
D1: D_Schottky; D_A-405_P7.62mm_Horizontal
J1: SPEAKER ENABLE; TerminalBlock_Phoenix_PT-1,5-2-3.5-H_1x02_P3.50mm_Horizontal
J2: DIGIT1; TerminalBlock_Phoenix_PT-1,5-9-3.5-H_1x09_P3.50mm_Horizontal
J3: DIGIT2; TerminalBlock_Phoenix_PT-1,5-9-3.5-H_1x09_P3.50mm_Horizontal
J4: DIGIT3; TerminalBlock_Phoenix_PT-1,5-9-3.5-H_1x09_P3.50mm_Horizontal
J5: DIGIT4; TerminalBlock_Phoenix_PT-1,5-9-3.5-H_1x09_P3.50mm_Horizontal
J6: DIGIT5; TerminalBlock_Phoenix_PT-1,5-9-3.5-H_1x09_P3.50mm_Horizontal
J7: DIGIT6; TerminalBlock_Phoenix_PT-1,5-9-3.5-H_1x09_P3.50mm_Horizontal
J8: AUX 12V OUT; PinHeader_1x02_P2.54mm_Vertical
J9, J10: Conn_01x03_Male; PinHeader_1x03_P2.54mm_Vertical
J11: 12V POW CONN; PinHeader_1x02_P2.54mm_Vertical
J12: 5V POW CONN; PinHeader_1x02_P2.54mm_Vertical
J13: AUX SINK; PinHeader_1x06_P2.54mm_Vertical
J14: AUX GPIO; PinHeader_1x05_P2.54mm_Vertical
J15: Barrel_Jack; BarrelJack_Kycon_KLDX-0202-xC_Horizontal
J16: CN3 Breakout; PinHeader_1x15_P2.54mm_Vertical
J17: CN3; PinHeader_1x15_P2.54mm_Vertical
J18: CN4; PinHeader_1x15_P2.54mm_Vertical
J19: CN4 Breakout; PinHeader_1x15_P2.54mm_Vertical
R1, R4, R7, R56, R57, R58, R59, R60, R61, R62: 0; R_0805_2012Metric_Pad1.20x1.40mm_HandSolder
R2, R3, R5, R6: 100k; R_0805_2012Metric_Pad1.20x1.40mm_HandSolder
R8, R9, R10, R11, R12, R13, R14, R15, R16, R17, R18, R19, R20, R21, R22, R23, R24, R25, R26, R27, R28, R29, R30, R31, R32, R33, R34, R35, R36, R37, R38, R39, R40, R41, R42, R43, R44, R45, R46, R47, R48, R49, R50, R51, R52, R53, R54, R55: 15; R_0805_2012Metric_Pad1.20x1.40mm_HandSolder
R63, R64, R65, R66, R67, R68, R69, R70, R71, R72, R73, R74, R75, R76, R77, R78, R79, R80, R81, R82, R83, R84, R85, R86: 120; R_0805_2012Metric_Pad1.20x1.40mm_HandSolder
U1, U2, U3, U10: TPIC6595; DIP-16_W7.62mm
U4, U5: J107F1CS1212VDC.36; Relay_SPDT_Finder_36.11
U6, U7, U8: HDSP-7501; HDSP-A151
U9: BD50FD0WFP; TO-263-5_TabPin6
U11, U12: TXU0104; TSSOP-14_4.4x5mm_P0.65mm

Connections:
+3V3: C7.1, C8.1, J14.2, J18.14, J19.14, U11.1 (VCCA), U11.8 (OE), U12.1 (VCCA), U12.8 (OE)
+5V: C1.2, C2.2, C3.2, C5.1, C6.2, C9.1, C10.1, J12.1, J14.1, R2.1, R5.1, U1.1 (VCC), U2.1 (VCC), U3.1 (VCC), U6.1 (CA), U6.6 (CA), U7.1 (CA), U7.6 (CA), U8.1 (CA), U8.6 (CA), U9.4 (VO), U10.1 (VCC), U11.14 (VCCB), U12.14 (VCCB)
+12V: C4.1, D1.1 (K), J2.1, J3.1, J4.1, J5.1, J6.1, J7.1, J11.1, U4.11 (COM), U4.A2 (COIL+), U5.11 (COM), U5.A2 (COIL+), U9.1 (EN), U9.2 (VCC)
/auxillary_sr/AUX_SR_1: R7.2, U10.3 (DRAIN0)
/auxillary_sr/AUX_SR_2: R56.2, U10.4 (DRAIN1)
/auxillary_sr/AUX_SR_3: R57.2, U10.5 (DRAIN2)
/auxillary_sr/AUX_SR_4: R58.2, U10.6 (DRAIN3)
/auxillary_sr/AUX_SR_5: R59.2, U10.11 (DRAIN4)
/auxillary_sr/AUX_SR_6: R60.2, U10.12 (DRAIN5)
/auxillary_sr/AUX_SR_7: R61.2, U10.13 (DRAIN6)
/auxillary_sr/AUX_SR_8: R62.2, U10.14 (DRAIN7)
/board_output/DIGIT1_1: R8.1, R32.1, R63.1, U1.3 (DRAIN0)
/board_output/DIGIT1_2: R9.1, R33.1, R64.1, U1.4 (DRAIN1)
/board_output/DIGIT1_3: R10.1, R34.1, R65.1, U1.5 (DRAIN2)
/board_output/DIGIT1_4: R11.1, R35.1, R66.1, U1.6 (DRAIN3)
/board_output/DIGIT1_5: R12.1, R36.1, R67.1, U1.11 (DRAIN4)
/board_output/DIGIT1_6: R13.1, R37.1, R68.1, U1.12 (DRAIN5)
/board_output/DIGIT1_7: R14.1, R38.1, R69.1, U1.13 (DRAIN6)
/board_output/DIGIT1_8: R15.1, R39.1, R70.1, U1.14 (DRAIN7)
/board_output/DIGIT2_1: R16.1, R40.1, R71.1, U2.3 (DRAIN0)
/board_output/DIGIT2_2: R17.1, R41.1, R72.1, U2.4 (DRAIN1)
/board_output/DIGIT2_3: R18.1, R42.1, R73.1, U2.5 (DRAIN2)
/board_output/DIGIT2_4: R19.1, R43.1, R74.1, U2.6 (DRAIN3)
/board_output/DIGIT2_5: R20.1, R44.1, R75.1, U2.11 (DRAIN4)
/board_output/DIGIT2_6: R21.1, R45.1, R76.1, U2.12 (DRAIN5)
/board_output/DIGIT2_7: R22.1, R46.1, R77.1, U2.13 (DRAIN6)
/board_output/DIGIT2_8: R23.1, R47.1, R78.1, U2.14 (DRAIN7)
/board_output/DIGIT3_1: R24.1, R48.1, R79.1, U3.3 (DRAIN0)
/board_output/DIGIT3_2: R25.1, R49.1, R80.1, U3.4 (DRAIN1)
/board_output/DIGIT3_3: R26.1, R50.1, R81.1, U3.5 (DRAIN2)
/board_output/DIGIT3_4: R27.1, R51.1, R82.1, U3.6 (DRAIN3)
/board_output/DIGIT3_5: R28.1, R52.1, R83.1, U3.11 (DRAIN4)
/board_output/DIGIT3_6: R29.1, R53.1, R84.1, U3.12 (DRAIN5)
/board_output/DIGIT3_7: R30.1, R54.1, R85.1, U3.13 (DRAIN6)
/board_output/DIGIT3_8: R31.1, R55.1, R86.1, U3.14 (DRAIN7)
/level_shifters/IN_3V3_1: J18.6, J19.6, U12.2 (A1)
/level_shifters/IN_3V3_2: J18.11, J19.11, U12.3 (A2)
/level_shifters/IN_3V3_3: J16.7, J17.7, U12.4 (A3)
/level_shifters/IN_3V3_4: J16.5, J17.5, U12.5 (A4)
/level_shifters/IN_3V3_5: J16.12, J17.12, U11.2 (A1)
/level_shifters/IN_3V3_6: J16.6, J17.6, U11.3 (A2)
/level_shifters/IN_3V3_7: J9.1, J16.10, J17.10, U11.4 (A3)
/level_shifters/IN_3V3_8: J10.1, J16.11, J17.11, U11.5 (A4)
/level_shifters/OUT_5V_1: U1.2 (SER_IN), U10.2 (SER_IN), U12.13 (B1)
/level_shifters/OUT_5V_2: U1.15 (SRCK), U2.15 (SRCK), U3.15 (SRCK), U10.15 (SRCK), U12.12 (B2)
/level_shifters/OUT_5V_3: R1.2, U12.11 (B3)
/level_shifters/OUT_5V_4: R4.2, U12.10 (B4)
/level_shifters/OUT_5V_5: U1.10 (RCK), U2.10 (RCK), U3.10 (RCK), U11.13 (B1)
/level_shifters/OUT_5V_6: U10.10 (RCK), U11.12 (B2)
/level_shifters/OUT_5V_7: J9.3, U11.11 (B3)
/level_shifters/OUT_5V_8: J10.3, U11.10 (B4)
/nCLR_PULLED: R1.1, R2.2, R3.1, U1.7 (CLR), U2.7 (CLR), U3.7 (CLR), U10.7 (CLR)
/nOE_PULLED: R4.1, R5.2, R6.1, U1.8 (G), U2.8 (G), U3.8 (G), U10.8 (G)
GND: C1.1, C2.1, C3.1, C4.2, C5.2, C6.1, C7.2, C8.2, C9.2, C10.2, J1.2, J8.2, J11.2, J12.2, J14.5, J15.2, J18.2, J19.2, R3.2, R6.2, U1.16 (GND), U2.16 (GND), U3.16 (GND), U9.3 (GND), U9.6, U10.16 (GND), U11.7 (GND), U12.7 (GND)
unnamed: D1.2 (A), J15.1
unnamed: J1.1, U4.12 (NO)
unnamed: J2.2, R8.2
unnamed: J2.3, R9.2
unnamed: J2.4, R10.2
unnamed: J2.5, R11.2
unnamed: J2.6, R12.2
unnamed: J2.7, R13.2
unnamed: J2.8, R14.2
unnamed: J2.9, R15.2
unnamed: J3.2, R16.2
unnamed: J3.3, R17.2
unnamed: J3.4, R18.2
unnamed: J3.5, R19.2
unnamed: J3.6, R20.2
unnamed: J3.7, R21.2
unnamed: J3.8, R22.2
unnamed: J3.9, R23.2
unnamed: J4.2, R24.2
unnamed: J4.3, R25.2
unnamed: J4.4, R26.2
unnamed: J4.5, R27.2
unnamed: J4.6, R28.2
unnamed: J4.7, R29.2
unnamed: J4.8, R30.2
unnamed: J4.9, R31.2
unnamed: J5.2, R32.2
unnamed: J5.3, R33.2
unnamed: J5.4, R34.2
unnamed: J5.5, R35.2
unnamed: J5.6, R36.2
unnamed: J5.7, R37.2
unnamed: J5.8, R38.2
unnamed: J5.9, R39.2
unnamed: J6.2, R40.2
unnamed: J6.3, R41.2
unnamed: J6.4, R42.2
unnamed: J6.5, R43.2
unnamed: J6.6, R44.2
unnamed: J6.7, R45.2
unnamed: J6.8, R46.2
unnamed: J6.9, R47.2
unnamed: J7.2, R48.2
unnamed: J7.3, R49.2
unnamed: J7.4, R50.2
unnamed: J7.5, R51.2
unnamed: J7.6, R52.2
unnamed: J7.7, R53.2
unnamed: J7.8, R54.2
unnamed: J7.9, R55.2
unnamed: J8.1, U5.12 (NO)
unnamed: J10.2, J14.4
unnamed: J13.1, R57.1
unnamed: J13.2, R58.1
unnamed: J13.3, R59.1
unnamed: J13.4, R60.1
unnamed: J13.5, R61.1
unnamed: J13.6, R62.1
unnamed: J9.2, J14.3
unnamed: R7.1, U4.A1 (COIL-)
unnamed: R56.1, U5.A1 (COIL-)
unnamed: R63.2, U6.10 (A)
unnamed: R64.2, U6.9 (B)
unnamed: R65.2, U6.8 (C)
unnamed: R66.2, U6.5 (D)
unnamed: R67.2, U6.4 (E)
unnamed: R68.2, U6.2 (F)
unnamed: R69.2, U6.3 (G)
unnamed: R70.2, U6.7 (DP)
unnamed: R71.2, U7.10 (A)
unnamed: R72.2, U7.9 (B)
unnamed: R73.2, U7.8 (C)
unnamed: R74.2, U7.5 (D)
unnamed: R75.2, U7.4 (E)
unnamed: R76.2, U7.2 (F)
unnamed: R77.2, U7.3 (G)
unnamed: R78.2, U7.7 (DP)
unnamed: R79.2, U8.10 (A)
unnamed: R80.2, U8.9 (B)
unnamed: R81.2, U8.8 (C)
unnamed: R82.2, U8.5 (D)
unnamed: R83.2, U8.4 (E)
unnamed: R84.2, U8.2 (F)
unnamed: R85.2, U8.3 (G)
unnamed: R86.2, U8.7 (DP)
unnamed: U1.9 (SER_OUT), U2.2 (SER_IN)
unnamed: U2.9 (SER_OUT), U3.2 (SER_IN)

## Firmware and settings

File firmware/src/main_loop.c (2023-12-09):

#include "main.h"
#include "spi.h"

#include "seven_seg_driver.h"
#include "shift_register.h"
#include "commands.h"
#include "timer.h"


uint8_t uart_rx_buffer[kCommandBufferLen];
uint8_t uart_tx_buffer[kCommandBufferLen];

/* HAL Objects */
UART_HandleTypeDef extern huart2;
SPI_HandleTypeDef* reg_spi = &hspi1;
extern TIM_HandleTypeDef htim16;

// GPIO Definitions
static gpio_output_t digit_rclk = { .port = GPIOA, .pin = GPIO_PIN_8 };
static gpio_output_t aux_rclk = { .port = GPIOB, .pin = GPIO_PIN_0 };
static gpio_output_t nuc_led = { .port = GPIOB, .pin = GPIO_PIN_3 };

/* Flags for callbacks*/
volatile bool onesec_timer_flag = false;
volatile bool uart_rx_flag = false;


/* Callbacks */
void HAL_TIM_PeriodElapsedCallback(TIM_HandleTypeDef *htim)
{
    onesec_timer_flag = true;
}

void HAL_UART_RxCpltCallback(UART_HandleTypeDef *huart)
{
    uart_rx_flag = true;
}

void NotifyTimerComplete()
{
    PopulateTimerCompleteNotification(uart_tx_buffer);
    HAL_UART_Transmit(&huart2, uart_tx_buffer, kCommandBufferLen, 100);
}


static bool led_state = false;
void MainLoop(void)
{
    ShiftRegister_Init();
    Timer_Init(&htim16);
    HAL_UART_Receive_IT(&huart2, uart_rx_buffer, kCommandBufferLen);
    GPIO_SetPin(nuc_led, led_state);

    for (;;) {
        // Handle UART
        if (uart_rx_flag) {
            uart_rx_flag = false;
            ProcessCommand(uart_rx_buffer, uart_tx_buffer);
            HAL_UART_Transmit(&huart2, uart_tx_buffer, kCommandBufferLen, 100);
            HAL_UART_Receive_IT(&huart2, uart_rx_buffer, kCommandBufferLen);
        }

        // Handle one second timer
        if (onesec_timer_flag) {
            GPIO_SetPin(nuc_led, led_state);
            led_state = !led_state;
            onesec_timer_flag = false;
            Timer_OneSecCallback();
        }

        // Wait a little bit
        HAL_Delay(1);
    }
}

/*

            // set the display
            uint8_t digit_1 = time_s / 100;
            uint8_t digit_2 = (time_s - digit_1) / 10;
            uint8_t digit_3 = (time_s - digit_1*100 - digit_2*10);
            shift_reg_bits_t digit_1_setting = SevenSegment_DigitToSetting(digit_1);
            shift_reg_bits_t digit_2_setting = SevenSegment_DigitToSetting(digit_2);
            shift_reg_bits_t digit_3_setting = SevenSegment_DigitToSetting(digit_3);

            SetDigitShiftRegisters(digit_1_setting, digit_2_setting, digit_3_setting);

            time_s -= 1;

*/

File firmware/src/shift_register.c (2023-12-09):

#include "shift_register.h"

#include "spi.h"

static gpio_output_t n_clr = { .port = GPIOB, .pin = GPIO_PIN_7 };
static gpio_output_t n_oe = { .port = GPIOA, .pin = GPIO_PIN_12 };

static gpio_output_t digit_rclk = { .port = GPIOA, .pin = GPIO_PIN_8 };
static gpio_output_t aux_rclk = { .port = GPIOB, .pin = GPIO_PIN_0 };

SPI_HandleTypeDef* shift_reg_spi = &hspi1;


void ShiftRegister_Init()
{
    ShiftRegister_ClearAll();
    ShiftRegister_EnableAll();
}

void ShiftRegister_ClearAll()
{
   GPIO_SetPin(n_clr, 0);
   HAL_Delay(1);
   GPIO_SetPin(n_clr, 1);
}

void ShiftRegister_EnableAll()
{
    GPIO_SetPin(n_oe, 0);
}

void ShiftRegister_DisableAll()
{
    GPIO_SetPin(n_oe, 1);
}

bool ShiftRegister_SendBits(shift_reg_bits_t bits)
{

    uint8_t data =
           bits.b1 << 7 |
           bits.b2 << 6 |
           bits.b3 << 5 |
           bits.b4 << 4 |
           bits.b5 << 3 |
           bits.b6 << 2 |
           bits.b7 << 1 |
           bits.b8 << 0;

/*
    uint8_t data[kShiftRegNBits] = {
        bits.b1,
        bits.b2, 
        bits.b3, 
        bits.b4, 
        bits.b5, 
        bits.b6, 
        bits.b7, 
        bits.b8};
*/
    HAL_StatusTypeDef res = HAL_SPI_Transmit(shift_reg_spi, &data, 1, 1000);
    return (res == HAL_OK);
}

void ShiftRegister_PulseRegClock(gpio_output_t clk)
{
    GPIO_SetPin(clk, 1);
    HAL_Delay(2);
    GPIO_SetPin(clk, 0);
}

bool SetDigitShiftRegisters(shift_reg_bits_t digit1, shift_reg_bits_t digit2, shift_reg_bits_t digit3)
{
    // Send the three digit bits in reverse order since they shift 1->2->3
    ShiftRegister_SendBits(digit3);
    ShiftRegister_SendBits(digit2);
    ShiftRegister_SendBits(digit1);

    ShiftRegister_PulseRegClock(digit_rclk);

    return true;
}

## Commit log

2023-12-09 PCB as sent to OSHPark 11/19/2023
    [arena-clock.csv, arena-clock.kicad_pcb, arena-clock.kicad_sch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]
2023-12-09 Add GPIO pin driver
2023-12-09 Add seven segment driver which sets up the segment structs
2023-12-09 Add shift register driver. Used primarily for driving the seven segment displays
2023-12-09 Add main loop. Currently implemeneted with a countdown from one hundred for testing.
2023-12-09 [Cube] Add UART interrupt to configuration. Decrease baud rate for UART to 9600.
2023-12-09 [Timer] Add timer state machine and digit setting capability
2023-12-09 [Commands] Add command proccessor to route commands received over UART and set up the response.
2023-12-09 Update main loop to use timer state machine and command processor. Add UART tx and rx handling.
2023-12-09 Add kicad backup directory to gitignore
2023-12-09 Update kicad schematic and layout with metadata (release date, title, company) and export pdfs as sent to mfg on 11/19.
    [arena-clock.kicad_pcb, arena-clock.kicad_sch, auxillary_sr.kicad_sch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]
2024-08-24 Fix typos causing error in gui
    [gui.py]
